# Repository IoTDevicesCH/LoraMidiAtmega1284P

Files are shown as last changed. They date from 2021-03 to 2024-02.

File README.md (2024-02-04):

# LoraMidi Atmega1284P
Special and small Lora(WAN) board using an Atmega1284P chip, RFM95 module, TPL5010 timer with optional watchdog function and switched GND pins. 



## Specialities about this board
- Arduino compatible
- Atmega1284P @ 8MHz with 128KB flash and 16KB RAM, easy replacement for Atmega328p boards
- Small form factor, 36.4mm lenght, 31.4mm width
- TPS782 low quiescent 500nA regulator
- RFM95 can be soldered to the bottom side
- Wire antenna, helical antenna, SMA antenna support
- TPL5010 can be used to wakeup the Atmega, with optional watchdog function
- Voltage divider on board, enabled through two MOSFET driven by pin 0
- I2C and 1-Wire pullups on board
- Input pin for interrupts with pullup resistor on board
- Two GND pins can be powered on/off through a MOSFET driven by pin 15 to power on/off external peripherals

## Board version 2.3
### Powering the board
Maximum input voltage on UREG pin: 5.5V<br>
Recommended minimum input voltage on UREG pin: 3.4V<br>
LDO maximum current: 150mA<br>
VCC on this board is 3.3V<br>
To power the board through VCC it is recommended to cut the trace from the LDO to VCC to reduce power consumption. See in the solder jumper section how to disable the LDO.<br>
### Sleep current without TPL5010 and RFM95, powered through the LDO:
Sleep current with WDT disabled and attached interrupt (1 minute average): approx 570nA<br>
Sleep current with WDT enabled (1 minute average): approx 6.1μA
### Sleep current with TPL5010 and without RFM95, powered through the LDO:
Sleep current with WDT disabled and TPL5010 attached as interrupt: approx 610nA
### Sleep current with TPL5010 and RFM95, powered through the LDO:
Sleep current with TPL5010 and RFM95, powered through the LDO: approx 1.5μA
### Sleep current with TPL5010 and without RFM95, powered through VCC (LDO disabled):
Sleep current with WDT disabled and TPL5010 attached as interrupt: approx 200nA

## Pinout
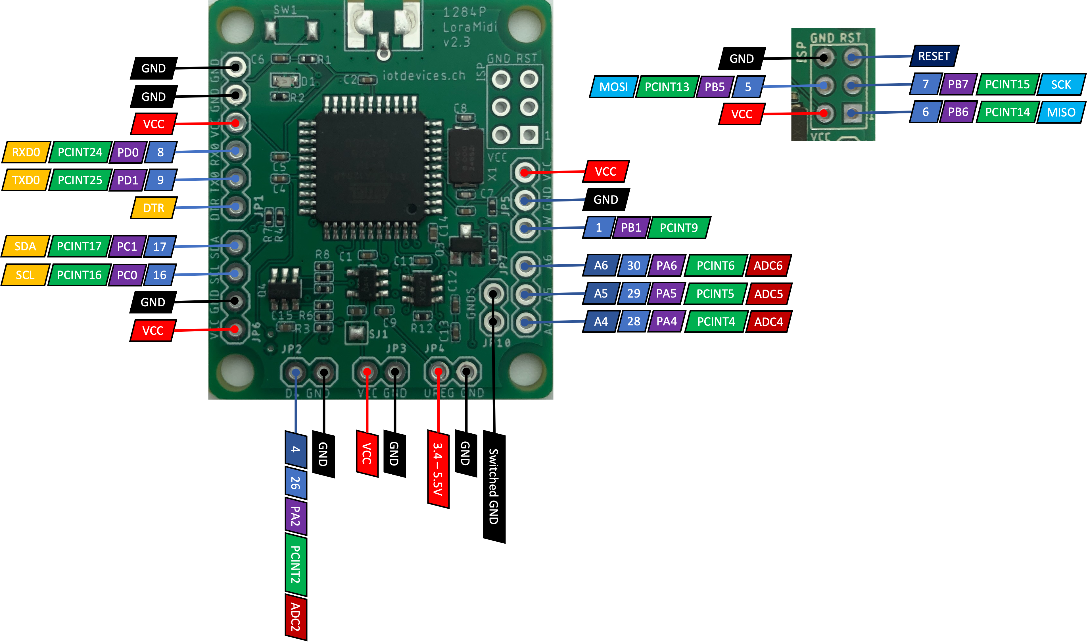
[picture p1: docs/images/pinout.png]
Pinout
<br>
The following pullups/pulldowns are already included on the board for easy usage:<br>
- Pin 1 / 1 Wire / 4.7K pullup
- Pin 16 / SDA, 4.7K pullup
- Pin 17 / SCL, 4.7K pullup
- Pin 4 / Interrupt / 10K pullup
<br>

## LMIC Pinmap
	#LMIC Pinmap
	const lmic_pinmap lmic_pins = {
		.nss = 14,
		.rxtx = LMIC_UNUSED_PIN,
		.rst = 13,
		.dio = {10, 11, 12},
	};

## Solder jumpers
The board has four solder jumpers.
### LDO on/off
- Top side, SJ1, closed = LDO on, open = LDO off
### Voltage divider UREG/VCC selection
- Bottom side, SJ2, left + middle connected = measure UREG, right + middle connected = measure VCC
### TPL5010 on/off
- Bottom side, SJ3, closed = TPL5010 powered, open = TPL5010 not powered
### TPL5010 WDT functionality on/off
- Bottom side, SJ4, closed = TPL5010 WDT on, open = TPL5010 WDT off
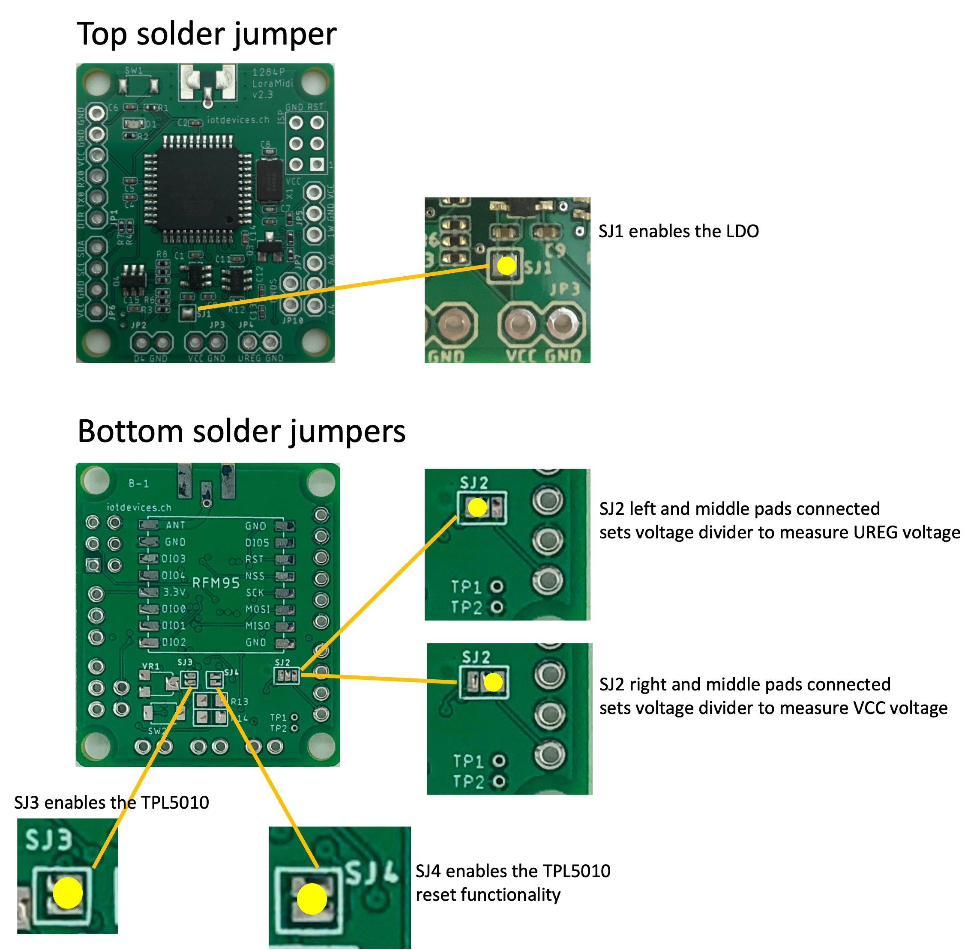
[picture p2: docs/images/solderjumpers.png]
Solderjumpers
<br><br><br>

## TPL5010 configuration
The TPL5010 provides selectable timing intervals through resistor(s). On the bottom side, R14, R15 and VR1 are wired in parallel.<br>
To set a fixed time interval, populate either one or both R14 and R15 resistors with the desired value resistors.<br>
To set a variable time interval, don't populate R14 and R15 but populate VR1 with a trimmpotentiometer.<br>
R14 and R15 are 0805 in size, the trimmpotentiometer pads are suited for the TC33X-2 line from Bourns.<br>
Please check the datasheet on page 14 and 15 of the TPL5010 for the available timing intervals: https://www.ti.com/lit/ds/symlink/tpl5010.pdf<br>

## How to get started
- Install current version of Arduino IDE
- Add the following additional board manager for Atmega1284P support from MightyCore: https://mcudude.github.io/MightyCore/package_MCUdude_MightyCore_index.json
  - Install version 2.2.2, starting with version 3.0.0, a new bootloader (Urboot) is used. Currently boards are still shipped with Optiboot bootloader
- Select the following settings in your Arduino IDE
  - Board: Atmega1284
  - Bootloader: Yes (UART0)
  - Pinout: Standard pinout
  - Clock: External 8 MHz
  - Compiler LTO: LTO disabled
  - EEPROM: EEPROM retained
  - Variant: 1284P
  - BOD: BOD Disabled

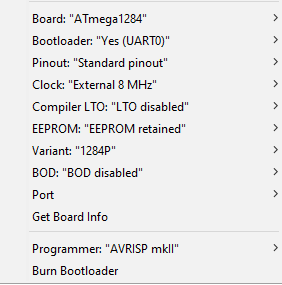
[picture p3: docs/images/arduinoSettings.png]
Arduino Settings


With the above settings you will be able to upload code through an FTDI adapter as with any other Arduino, like the MiniPro.

## More accurate supply voltage measurement
If you want a more accurate reading of the supply voltage, use the AREF value from the sticker on the board.

## Device pictures
# Device
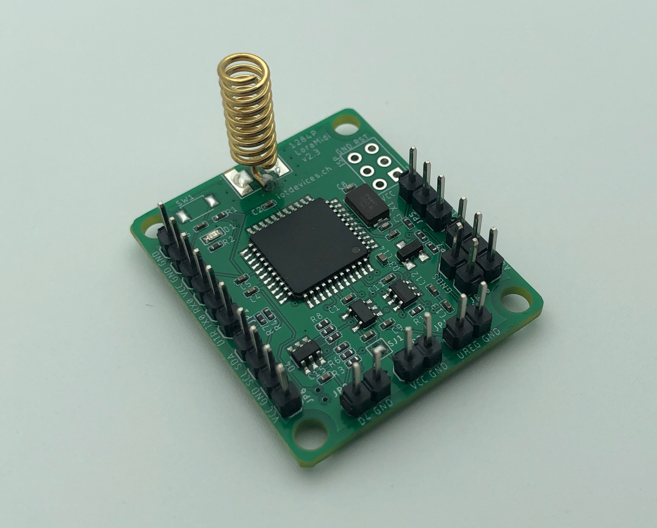
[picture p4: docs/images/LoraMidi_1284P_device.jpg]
Device


# Top view
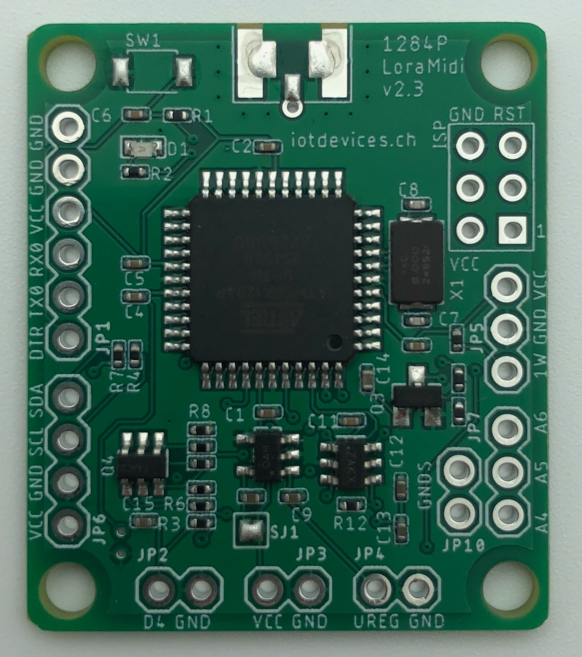
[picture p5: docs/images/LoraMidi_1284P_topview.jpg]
Top view


# Bottom view
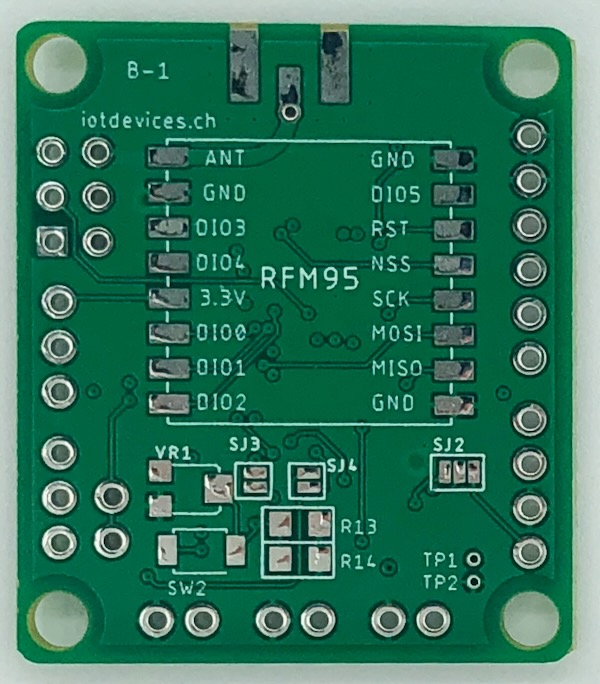
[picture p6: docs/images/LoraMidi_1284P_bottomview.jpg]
Bottom view


# Measurements
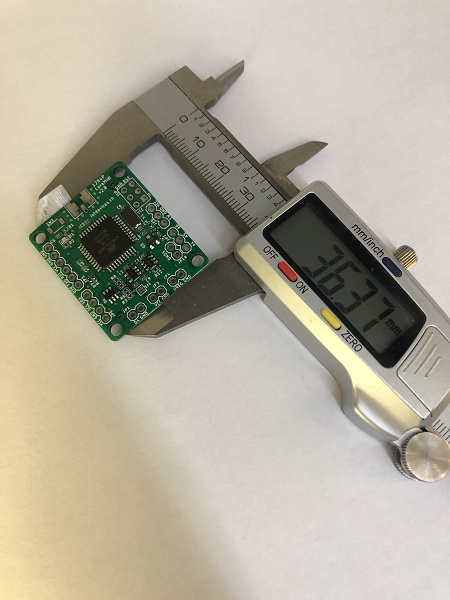
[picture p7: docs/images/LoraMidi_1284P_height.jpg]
Height
<br>
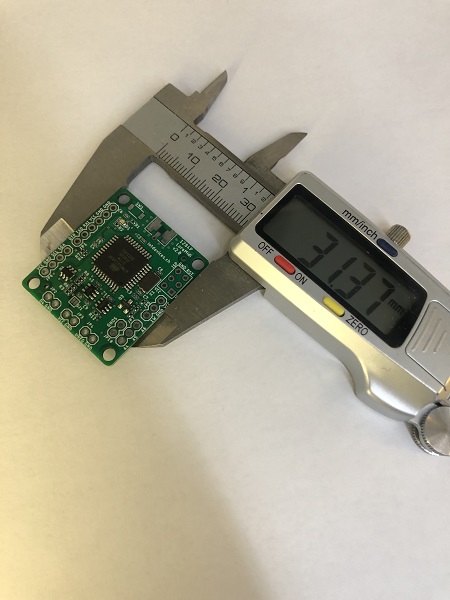
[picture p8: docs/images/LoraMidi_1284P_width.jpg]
Width


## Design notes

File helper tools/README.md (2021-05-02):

# LoraMidi Atmega1284P helper tools
Here you will find some handy tools for easier usage of the LoraMidi Atmega1284P board.

## Header solder helper 3D model
- Atmega_1284P_LoraMidi_header_solderhelber.stl is meant to help you to straight solder your pin headers.
- 0.4mm nozzle width
- 0.1mm layer height
- no supports

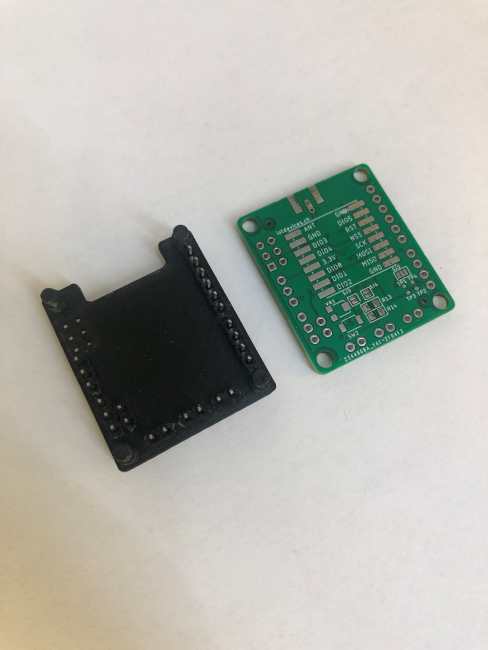
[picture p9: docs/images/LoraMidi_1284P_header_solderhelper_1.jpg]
LoraMidi_1284P_header_solderhelper_1
<br>
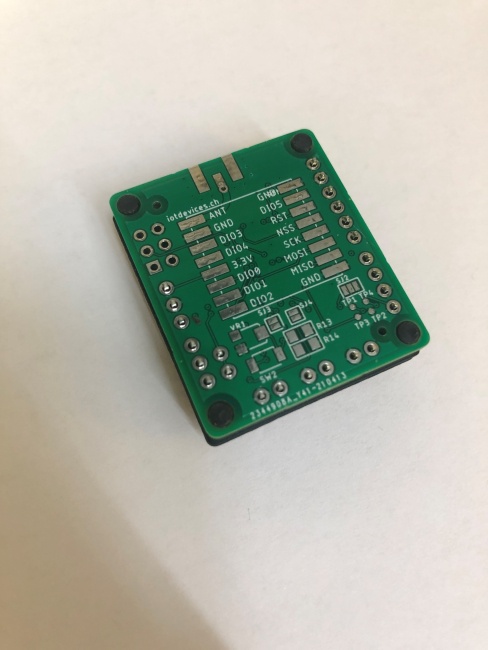
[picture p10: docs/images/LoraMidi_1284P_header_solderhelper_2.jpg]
LoraMidi_1284P_header_solderhelper_2
<br>
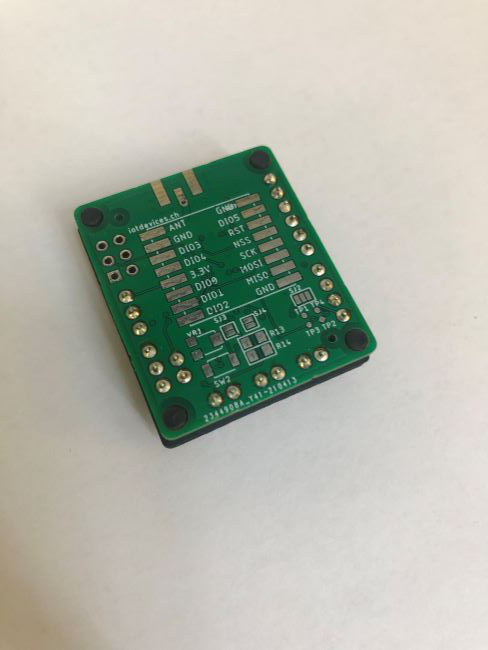
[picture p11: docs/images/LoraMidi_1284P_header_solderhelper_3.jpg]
LoraMidi_1284P_header_solderhelper_3


## Coil antenna solder helper 3D model
- Atmega_1284P_Atmega_1284P_LoraMidi_coil_antenna_solderhelper.stl is meant to help you to straight solder your coil antenna.
- 0.4mm nozzle width
- 0.1mm layer height
- lay flat, with supports

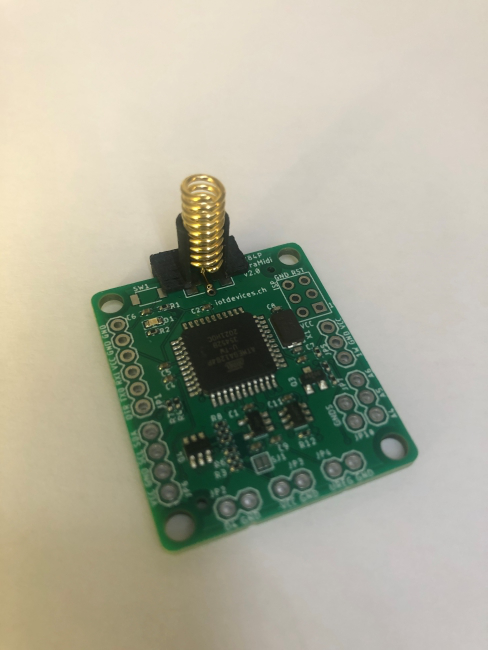
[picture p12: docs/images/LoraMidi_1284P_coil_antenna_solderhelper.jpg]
LoraMidi_1284P_coil_antenna_solderhelper


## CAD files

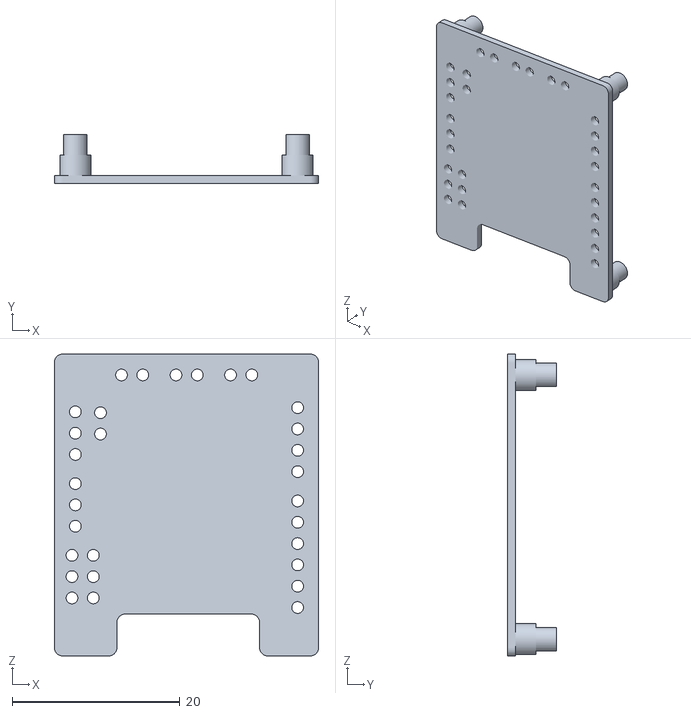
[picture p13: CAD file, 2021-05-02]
helper tools/Atmega_1284P_LoraMidi_header_solderhelper.stl
31.5 x 5.90 x 36.0

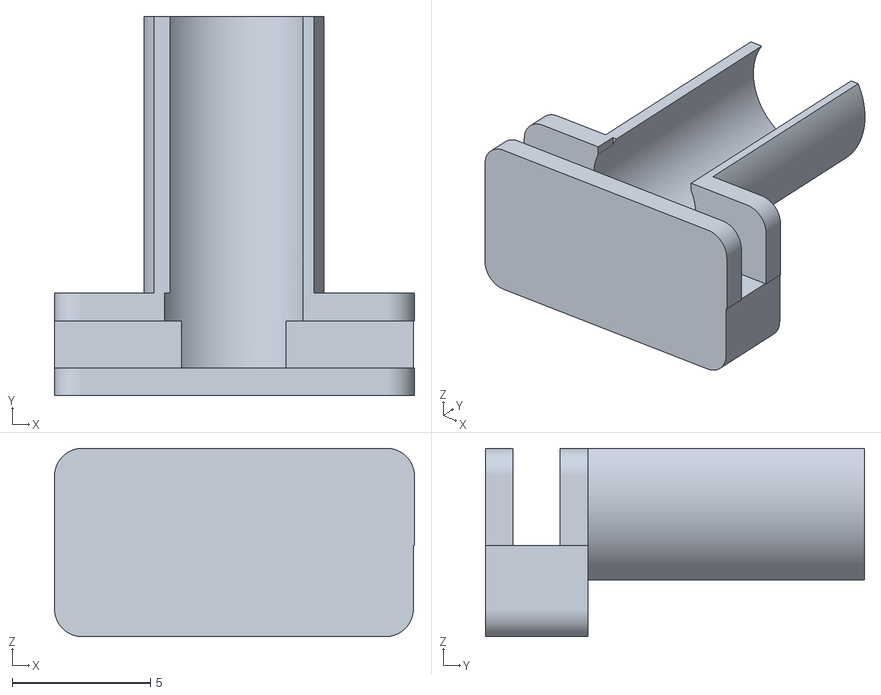
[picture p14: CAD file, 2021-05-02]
helper tools/Atmega_1284P_LoraMidi_coil_antenna_solderhelper.stl
13.0 x 13.7 x 6.80

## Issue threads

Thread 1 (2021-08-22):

use os_setCallback() instead of hacking timer

pierregremaud, 2021-08-22:
This is not an issue, but more a proposition.

In ttn-otaa-sleepWDT.ino you use the following code (lines 262 .. 266)

            // LMIC uses micros() to keep track of the duty cycle, so
            // hack timer0_overflow for a rude adjustment:
            cli();
            timer0_overflow_count += 8 * 64 * clockCyclesPerMicrosecond();
            sei();

I would just delete them and change line 270

        do_send(&sendjob);

to the following 👍

          os_setCallback(&sendjob, do_send);

I have tried and it seems to work fine... So no need to hack the timer...

Regards

Pierre Gremaud

IoTDevicesCH, 2021-09-25:
Hello, thank you for the input. I tested this and yes, this looks like a better solution. I will update the examples soon!

IoTDevicesCH, 2021-09-25:
I tested a bit further, only setting
`os_setCallback(&sendjob, do_send); `
will cause delay in the transmission, therefore power consumption is higher.

Better to use
```
timer0_overflow_count += 8 * 64 * clockCyclesPerMicrosecond();
os_setCallback(&sendjob, do_send);
```
The two lines
```
cli();
sei();
```
are not necessary, I will update the examples soon.

Closed 2021-09-25.

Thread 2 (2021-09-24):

Thank you for the boards!

SensorsIot, 2021-09-24:
I did not find an email to contact you. Maybe you contact me electronically?

IoTDevicesCH, 2021-09-24:
> I did not find an email to contact you. Maybe you contact me electronically?

contacted you on Facebook! :)  you can also reach me at meier (at) matias (dot) ch

Closed 2021-09-24.

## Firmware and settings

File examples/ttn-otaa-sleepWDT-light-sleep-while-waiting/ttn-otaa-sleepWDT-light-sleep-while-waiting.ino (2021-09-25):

// This sketch demonstrates how to use the internal WDT of the Atmega 1284P to sleep between transmissions to reduce power consumption.
// As an addition, in this sketch the MCU goes into idle state for multiples of 1ms to save power while waiting for the RFM95 module to complete TX or wait for RX window.
// This saves about 60% of power while waiting instead of letting the MCU simply powered on in normal mode.

/*******************************************************************************
 * Copyright (c) 2015 Thomas Telkamp and Matthijs Kooijman
 * Copyright (c) 2018 Terry Moore, MCCI
 *
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
 * This example sends a valid LoRaWAN packet with payload "Hello,
 * world!", using frequency and encryption settings matching those of
 * the The Things Network.
 *
 * This uses OTAA (Over-the-air activation), where where a DevEUI and
 * application key is configured, which are used in an over-the-air
 * activation procedure where a DevAddr and session keys are
 * assigned/generated for use with all further communication.
 *
 * Note: LoRaWAN per sub-band duty-cycle limitation is enforced (1% in
 * g1, 0.1% in g2), but not the TTN fair usage policy (which is probably
 * violated by this sketch when left running for longer)!

 * To use this sketch, first register your application and device with
 * the things network, to set or generate an AppEUI, DevEUI and AppKey.
 * Multiple devices can use the same AppEUI, but each device has its own
 * DevEUI and AppKey.
 *
 * Do not forget to define the radio type correctly in
 * arduino-lmic/project_config/lmic_project_config.h or from your BOARDS.txt.
 *
 *******************************************************************************/

#include <lmic.h>
#include <hal/hal.h>
#include <SPI.h>
#include <LowPower.h>
bool next = false;

//
// For normal use, we require that you edit the sketch to replace FILLMEIN
// with values assigned by the TTN console. However, for regression tests,
// we want to be able to compile these scripts. The regression tests define
// COMPILE_REGRESSION_TEST, and in that case we define FILLMEIN to a non-
// working but innocuous value.
//
//# define COMPILE_REGRESSION_TEST //comment this out if you want to compile this sketch with 'FILLMEIN' values for APPEUI, DEVEUI and APPKEY
#ifdef COMPILE_REGRESSION_TEST
# define FILLMEIN 0
#else
# warning "You must replace the values marked FILLMEIN with real values from the TTN control panel!"
# define FILLMEIN (#dont edit this, edit the lines that use FILLMEIN)
#endif

// This EUI must be in little-endian format, so least-significant-byte
// first. When copying an EUI from ttnctl output, this means to reverse
// the bytes. For TTN issued EUIs the last bytes should be 0xD5, 0xB3,
// 0x70.
static const u1_t PROGMEM APPEUI[8] = { FILLMEIN };
void os_getArtEui (u1_t* buf) { memcpy_P(buf, APPEUI, 8);}

// This should also be in little endian format, see above.
static const u1_t PROGMEM DEVEUI[8] = { FILLMEIN };
void os_getDevEui (u1_t* buf) { memcpy_P(buf, DEVEUI, 8);}

// This key should be in big endian format (or, since it is not really a
// number but a block of memory, endianness does not really apply). In
// practice, a key taken from ttnctl can be copied as-is.
static const u1_t PROGMEM APPKEY[16] = { FILLMEIN };
void os_getDevKey (u1_t* buf) {  memcpy_P(buf, APPKEY, 16);}

static uint8_t mydata[] = "Hello, world!";
static osjob_t sendjob;

// Schedule TX every this many seconds (might become longer due to duty
// cycle limitations).
const unsigned TX_INTERVAL = 120;

// Pin mapping
const lmic_pinmap lmic_pins = {
    .nss = 14,
    .rxtx = LMIC_UNUSED_PIN,
    .rst = 13,
    .dio = {10, 11, 12},
};

void printHex2(unsigned v) {
    v &= 0xff;
    if (v < 16)
        Serial.print('0');
    Serial.print(v, HEX);
}

void onEvent (ev_t ev) {
    Serial.print(os_getTime());
    Serial.print(": ");
    switch(ev) {
        case EV_SCAN_TIMEOUT:
            Serial.println(F("EV_SCAN_TIMEOUT"));
            break;
        case EV_BEACON_FOUND:
            Serial.println(F("EV_BEACON_FOUND"));
            break;
        case EV_BEACON_MISSED:
            Serial.println(F("EV_BEACON_MISSED"));
            break;
        case EV_BEACON_TRACKED:
            Serial.println(F("EV_BEACON_TRACKED"));
            break;
        case EV_JOINING:
            Serial.println(F("EV_JOINING"));
            break;
        case EV_JOINED:
            Serial.println(F("EV_JOINED"));
            {
              u4_t netid = 0;
              devaddr_t devaddr = 0;
              u1_t nwkKey[16];
              u1_t artKey[16];
              LMIC_getSessionKeys(&netid, &devaddr, nwkKey, artKey);
              Serial.print("netid: ");
              Serial.println(netid, DEC);
              Serial.print("devaddr: ");
              Serial.println(devaddr, HEX);
              Serial.print("AppSKey: ");
              for (size_t i=0; i<sizeof(artKey); ++i) {
                if (i != 0)
                  Serial.print("-");
                printHex2(artKey[i]);
              }
              Serial.println("");
              Serial.print("NwkSKey: ");
              for (size_t i=0; i<sizeof(nwkKey); ++i) {
                      if (i != 0)
                              Serial.print("-");
                      printHex2(nwkKey[i]);
              }
              Serial.println();
            }
            // Disable link check validation (automatically enabled
            // during join, but because slow data rates change max TX
	    // size, we don't use it in this example.
            LMIC_setLinkCheckMode(0);
            break;
        /*
        || This event is defined but not used in the code. No
        || point in wasting codespace on it.
        ||
        || case EV_RFU1:
        ||     Serial.println(F("EV_RFU1"));
        ||     break;
        */
        case EV_JOIN_FAILED:
            Serial.println(F("EV_JOIN_FAILED"));
            break;
        case EV_REJOIN_FAILED:
            Serial.println(F("EV_REJOIN_FAILED"));
            break;
        case EV_TXCOMPLETE:
            Serial.println(F("EV_TXCOMPLETE (includes waiting for RX windows)"));
            if (LMIC.txrxFlags & TXRX_ACK)
              Serial.println(F("Received ack"));
            if (LMIC.dataLen) {
              Serial.print(F("Received "));
              Serial.print(LMIC.dataLen);
              Serial.println(F(" bytes of payload"));
            }
            // Schedule next transmission
            next = true;
            //os_setTimedCallback(&sendjob, os_getTime()+sec2osticks(TX_INTERVAL), do_send);
            break;
        case EV_LOST_TSYNC:
            Serial.println(F("EV_LOST_TSYNC"));
            break;
        case EV_RESET:
            Serial.println(F("EV_RESET"));
            break;
        case EV_RXCOMPLETE:
            // data received in ping slot
            Serial.println(F("EV_RXCOMPLETE"));
            break;
        case EV_LINK_DEAD:
            Serial.println(F("EV_LINK_DEAD"));
            break;
        case EV_LINK_ALIVE:
            Serial.println(F("EV_LINK_ALIVE"));
            break;
        /*
        || This event is defined but not used in the code. No
        || point in wasting codespace on it.
        ||
        || case EV_SCAN_FOUND:
        ||    Serial.println(F("EV_SCAN_FOUND"));
        ||    break;
        */
        case EV_TXSTART:
            Serial.println(F("EV_TXSTART"));
            break;
        case EV_TXCANCELED:
            Serial.println(F("EV_TXCANCELED"));
            break;
        case EV_RXSTART:
            /* do not print anything -- it wrecks timing */
            break;
        case EV_JOIN_TXCOMPLETE:
            Serial.println(F("EV_JOIN_TXCOMPLETE: no JoinAccept"));
            break;

        default:
            Serial.print(F("Unknown event: "));
            Serial.println((unsigned) ev);
            break;
    }
}

void do_send(osjob_t* j){
    // Check if there is not a current TX/RX job running
    if (LMIC.opmode & OP_TXRXPEND) {
        Serial.println(F("OP_TXRXPEND, not sending"));
    } else {
        // Prepare upstream data transmission at the next possible time.
        LMIC_setTxData2(1, mydata, sizeof(mydata)-1, 0);
        Serial.println(F("Packet queued"));
    }
    // Next TX is scheduled after TX_COMPLETE event.
}

void setup() {
    Serial.begin(115200);
    Serial.println("Starting");

    #ifdef VCC_ENABLE
    // For Pinoccio Scout boards
    pinMode(VCC_ENABLE, OUTPUT);
    digitalWrite(VCC_ENABLE, HIGH);
    delay(1000);
    #endif

    // LMIC init
    os_init();
    // Reset the MAC state. Session and pending data transfers will be discarded.
    LMIC_reset();

    // Start job (sending automatically starts OTAA too)
    do_send(&sendjob);
}

void loop() {
    extern volatile unsigned long timer0_overflow_count;
    if (next == false) {
        os_runloop_once();

        // If we've to wait for the RFM95 module to complete TX or wait for RX window can't powerDown the MCU,
        // as LMIC controls RX timing and LMIC uses micros(), powerDown would stop micros() from running.
        // Instead we can put the MCU into idle state with TIMER0_ON for whatever time interval (SLEEP_8S used below), 
        // as TIMER0 will overflow every 1ms, MCU will wake up every ms again. We can save about 60% of the power during
        // waiting with this simple trick.

        // Check if any time critical jobs is due in the next 1ms
        if (os_queryTimeCriticalJobs(ms2osticks(1)) == 0) {
            // If no time critical job is due, enter idle mode for 1ms
            LowPower.idle(SLEEP_8S, ADC_OFF, TIMER2_OFF, TIMER1_OFF, TIMER0_ON, SPI_OFF, USART1_OFF, USART0_OFF, TWI_OFF);
        }
    }
    else {
        int sleepCycles = TX_INTERVAL / 8; // how often we go to sleep for 8 seconds
        for (int i = 0; i < sleepCycles; i++) {
            // Enter power down state for 8 s with ADC and BOD module disabled
            LowPower.powerDown(SLEEP_8S, ADC_OFF, BOD_OFF);

            // LMIC uses micros() to keep track of the duty cycle, so
            // hack timer0_overflow for a rude adjustment:
            timer0_overflow_count += 8 * 64 * clockCyclesPerMicrosecond();
        }
        next = false;
        // Start job
        do_send(&sendjob);
    }
}

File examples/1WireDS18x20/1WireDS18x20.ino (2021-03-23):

// OneWire DS18S20, DS18B20, DS1822 Temperature Example
//
// http://www.pjrc.com/teensy/td_libs_OneWire.html
//
// The DallasTemperature library can do all this work for you!
// http://milesburton.com/Dallas_Temperature_Control_Library
#include <OneWire.h>

OneWire  ds(1);  // on pin 1, the necessary 4.7K resistor is already soldered to the board

void setup(void) {
  Serial.begin(115200);
  Serial.println("Starting");
}

void loop(void) {
  byte i;
  byte present = 0;
  byte type_s;
  byte data[12];
  byte addr[8];
  float celsius, fahrenheit;
  
  if ( !ds.search(addr)) {
    Serial.println("No more addresses.");
    Serial.println();
    ds.reset_search();
    delay(250);
    return;
  }
  
  Serial.print("ROM =");
  for( i = 0; i < 8; i++) {
    Serial.write(' ');
    Serial.print(addr[i], HEX);
  }

  if (OneWire::crc8(addr, 7) != addr[7]) {
      Serial.println("CRC is not valid!");
      return;
  }
  Serial.println();
 
  // the first ROM byte indicates which chip
  switch (addr[0]) {
    case 0x10:
      Serial.println("  Chip = DS18S20");  // or old DS1820
      type_s = 1;
      break;
    case 0x28:
      Serial.println("  Chip = DS18B20");
      type_s = 0;
      break;
    case 0x22:
      Serial.println("  Chip = DS1822");
      type_s = 0;
      break;
    default:
      Serial.println("Device is not a DS18x20 family device.");
      return;
  } 

  ds.reset();
  ds.select(addr);
  ds.write(0x44, 1);        // start conversion, with parasite power on at the end
  
  delay(1000);     // maybe 750ms is enough, maybe not
  // we might do a ds.depower() here, but the reset will take care of it.
  
  present = ds.reset();
  ds.select(addr);    
  ds.write(0xBE);         // Read Scratchpad

  Serial.print("  Data = ");
  Serial.print(present, HEX);
  Serial.print(" ");
  for ( i = 0; i < 9; i++) {           // we need 9 bytes
    data[i] = ds.read();
    Serial.print(data[i], HEX);
    Serial.print(" ");
  }
  Serial.print(" CRC=");
  Serial.print(OneWire::crc8(data, 8), HEX);
  Serial.println();

  // Convert the data to actual temperature
  // because the result is a 16 bit signed integer, it should
  // be stored to an "int16_t" type, which is always 16 bits
  // even when compiled on a 32 bit processor.
  int16_t raw = (data[1] << 8) | data[0];
  if (type_s) {
    raw = raw << 3; // 9 bit resolution default
    if (data[7] == 0x10) {
      // "count remain" gives full 12 bit resolution
      raw = (raw & 0xFFF0) + 12 - data[6];
    }
  } else {
    byte cfg = (data[4] & 0x60);
    // at lower res, the low bits are undefined, so let's zero them
    if (cfg == 0x00) raw = raw & ~7;  // 9 bit resolution, 93.75 ms
    else if (cfg == 0x20) raw = raw & ~3; // 10 bit res, 187.5 ms
    else if (cfg == 0x40) raw = raw & ~1; // 11 bit res, 375 ms
    //// default is 12 bit resolution, 750 ms conversion time
  }
  celsius = (float)raw / 16.0;
  fahrenheit = celsius * 1.8 + 32.0;
  Serial.print("  Temperature = ");
  Serial.print(celsius);
  Serial.print(" Celsius, ");
  Serial.print(fahrenheit);
  Serial.println(" Fahrenheit");
}

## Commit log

2021-04-20 added low power ttn-otaa examples
2021-05-02 added 3D models to help manual soldering process
    [Atmega_1284P_LoraMidi_coil_antenna_solderhelper.stl, Atmega_1284P_LoraMidi_header_solderhelper.stl]
